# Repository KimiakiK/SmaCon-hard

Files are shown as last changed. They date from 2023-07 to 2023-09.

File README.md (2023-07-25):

# SmaCon-hard

# Features
- 

# Major Components
- STM32U575CIU6Q
Arm Cortex-M33 160MHz ROM 2MB RAM 786KB UFQFPN-48
- LCD
2.8inch 240x320 IPS ST7789 Touch GT911
- YMF825
FM音源
- 振動モータ
LD14-002

# Photos

# Parts List
- [STM32U575CIU6Q](https://mou.sr/46YhdRg)
- LCD (AliExpress)
- FM音源 YMF825 (AliExpress)
- [スピーカー](https://akizukidenshi.com/catalog/g/gP-12495/)
- [水晶振動子 12.228MHz](https://www.marutsu.co.jp/pc/i/1542722/)
- [3.5mmステレオミニジャック](https://www.marutsu.co.jp/pc/i/590750/)
- [EEPROM 1KB 25LC080C-E/MS](https://mou.sr/3XQXcYr)
- [振動モータ LD14-002](https://akizukidenshi.com/catalog/g/gP-06838/)
- [モータドライバ BD6211F](https://akizukidenshi.com/catalog/g/gI-05087/)
- [USB Type-Cコネクタ 5077CR-16SMC2-BK-TR](https://akizukidenshi.com/catalog/g/gC-14356/)
- [アナログジョイスティック JT8P-3.2T-B10K-1-16Y](https://akizukidenshi.com/catalog/g/gP-04048/)
- [タクトスイッチ(赤)](https://akizukidenshi.com/catalog/g/gP-03646/)
- [タクトスイッチ(黄)](https://akizukidenshi.com/catalog/g/gP-03650/)
- [タクトスイッチ(緑)](https://akizukidenshi.com/catalog/g/gP-03651/)
- [タクトスイッチ(青)](https://akizukidenshi.com/catalog/g/gP-03649/)
- [レバースイッチ TMHU27](https://akizukidenshi.com/catalog/g/gP-08071/)
- [リセットIC BD45285G 2.5V 50ms](https://www.marutsu.co.jp/pc/i/16146424/)
- [レギュレータ NJM2884U1-33 3.3V 500mA](https://akizukidenshi.com/catalog/g/gI-10673/)
- [ESD保護デバイス LXES11DAA2-137](https://akizukidenshi.com/catalog/g/gP-13816/)
- [フェライトビーズ BLM18PG600SH1](https://akizukidenshi.com/catalog/g/gP-04442/)
- [リセッタブルヒューズ 0.5A MF-NSMF050](https://akizukidenshi.com/catalog/g/gP-15300/)
- [NchパワーMOSFET AO3400A](https://akizukidenshi.com/catalog/g/gI-14653/)
- [FFCコネクタ 18pin 0.5mm](https://www.marutsu.co.jp/pc/i/2572902/)
- [FFCコネクタ 6pin 0.5mm](https://www.marutsu.co.jp/pc/i/2572910/)

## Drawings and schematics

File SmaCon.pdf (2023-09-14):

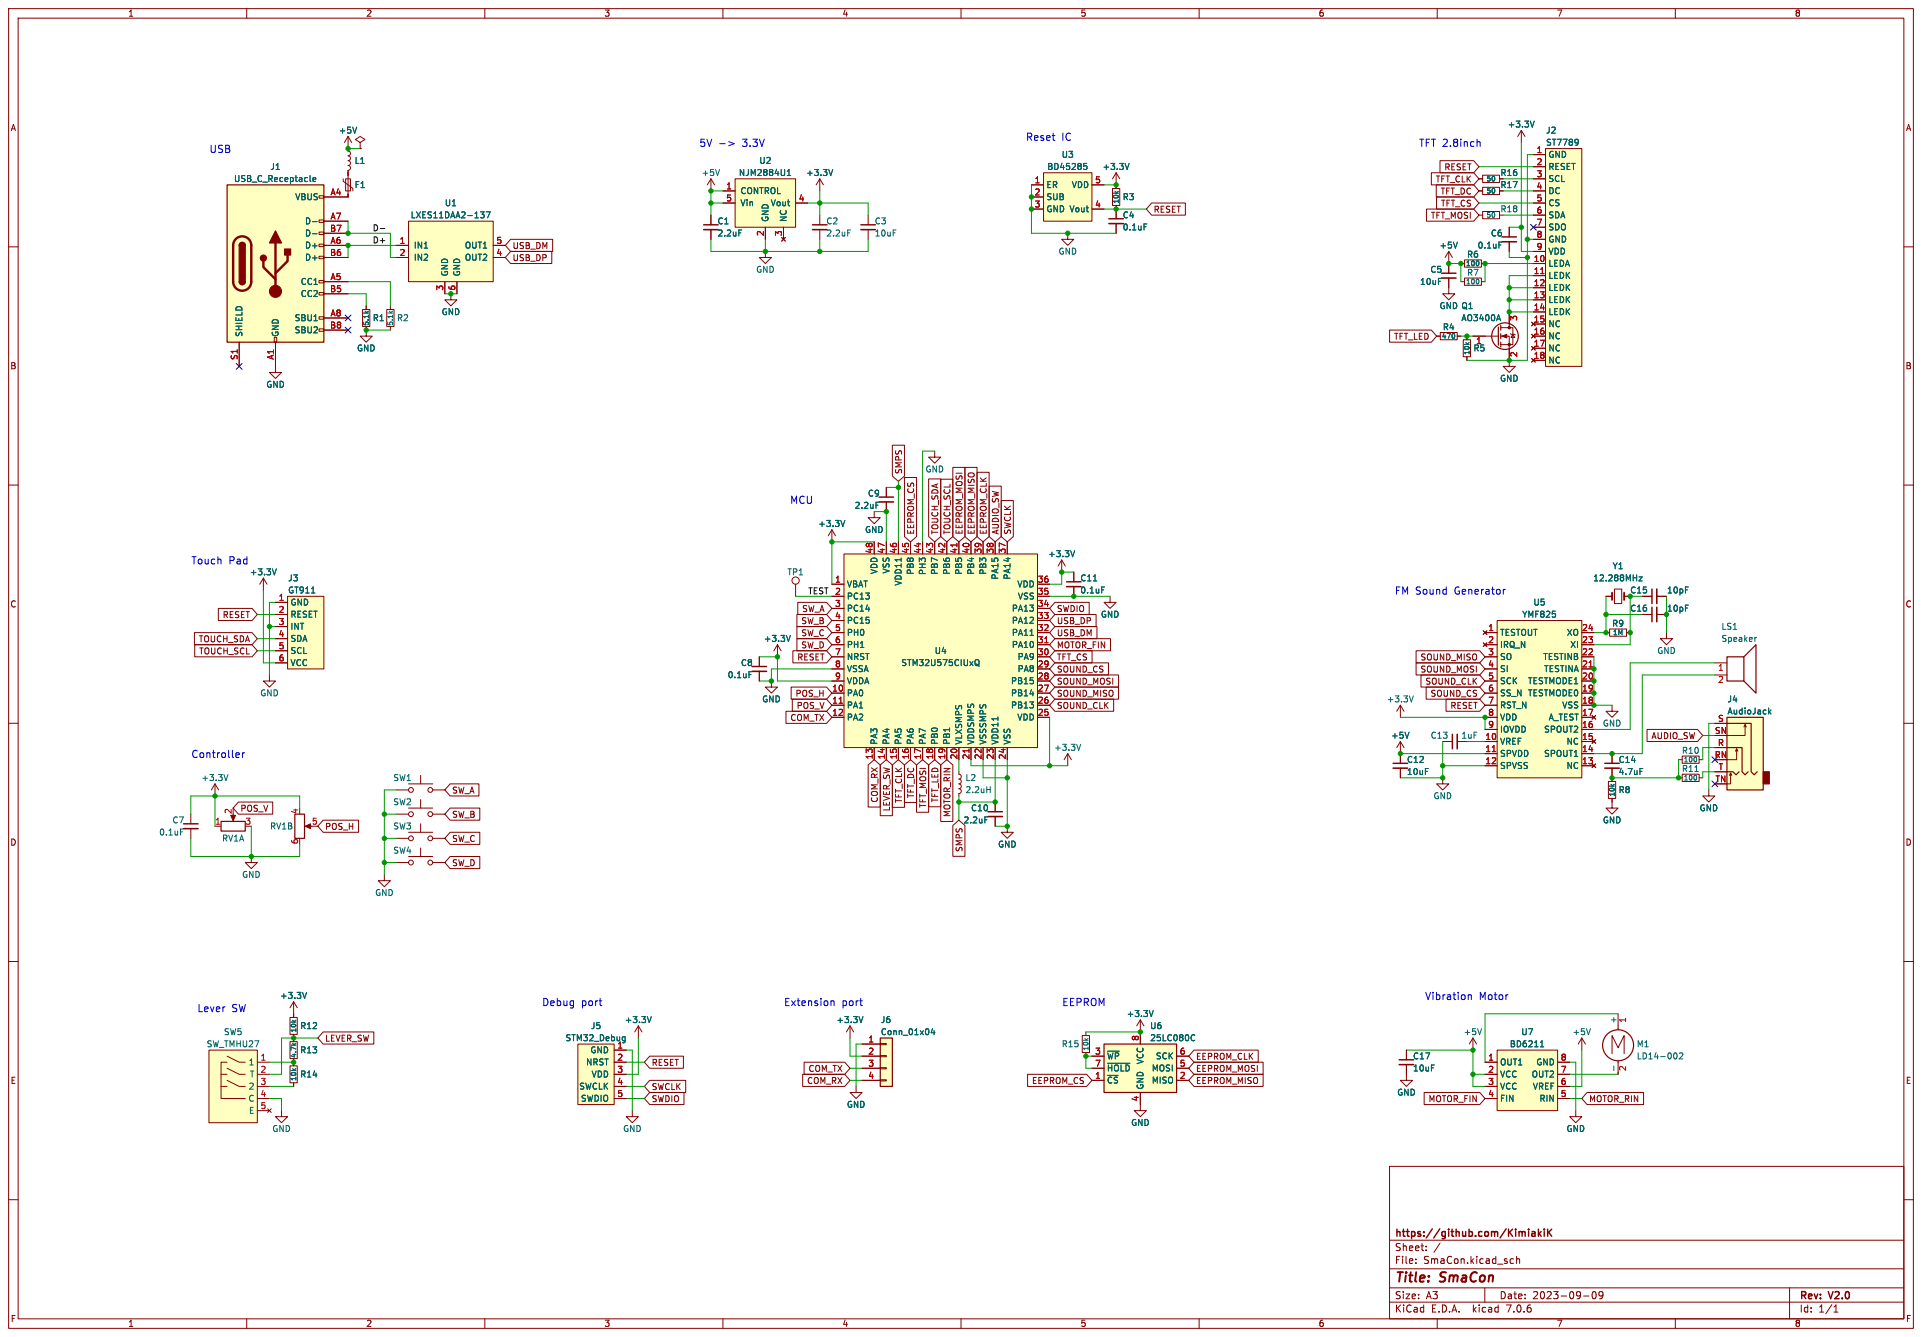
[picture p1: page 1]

LEDK 14 NC 15 NC 16 NC 17 NC 18 RESET 2 SCL 3 DC 4 CS 5 SDA 6 SDO 7 GND 8 VDD 9

LEDK 14 NC 15 NC 16 NC 17 NC 18 RESET 2 SCL 3 DC 4 CS 5 SDA 6 SDO 7 GND 8 VDD 9 R5 10k Q1 AO3400A
RESET
TFT_CLK
TFT_DC
TFT_MOSI TFT_CS

J5 STM32_Debug
GND 1 NRST 2 VDD 3 SWCLK 4 SWDIO 5

4 MOSI 5 SCK 6 ~{HOLD} 7 VCC

File: SmaCon.kicad_sch Sheet: / https://github.com/KimiakiK

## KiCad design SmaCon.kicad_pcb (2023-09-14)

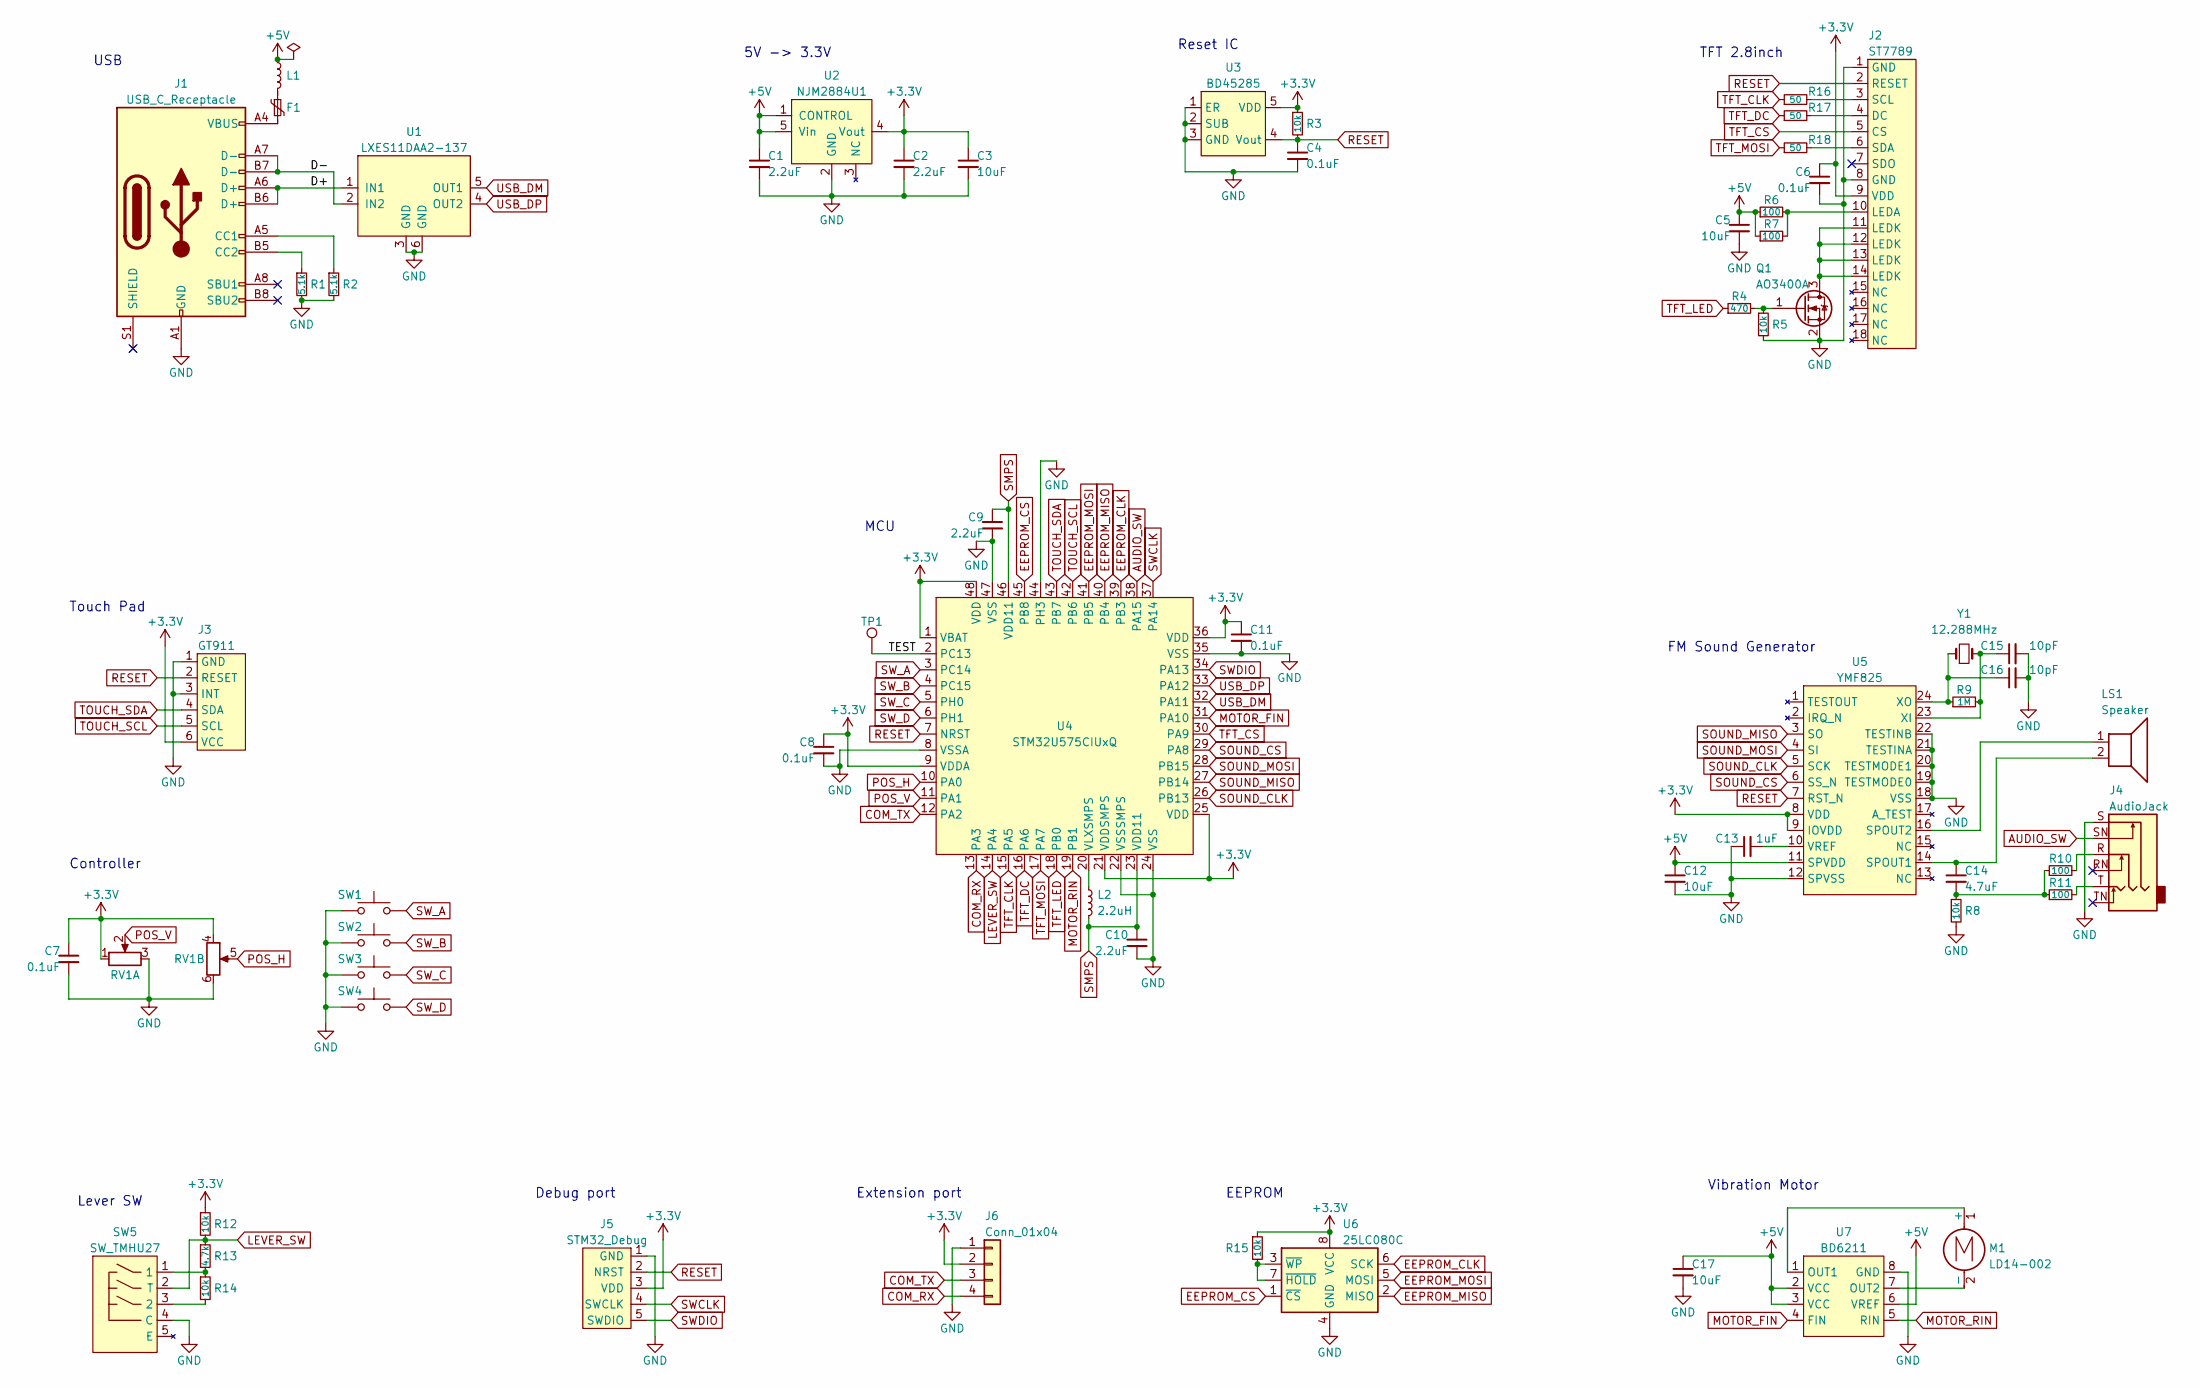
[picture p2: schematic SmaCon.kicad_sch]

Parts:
C1, C2, C9, C10: 2.2uF; 1005Metric
C3, C5, C12, C17: 10uF; 1608Metric
C4, C6, C7, C8, C11: 0.1uF; 1005Metric
C13: 1uF; 1005Metric
C14: 4.7uF; 1608Metric
C15, C16: 10pF; 1005Metric
F1: Polyfuse; 3216Metric
J1: USB_C_Receptacle; USB Type-C 5077CR-16SMC2-BK-TR
J2: ST7789; Hirose_FH12-18S-0.5SH_1x18-1MP_P0.50mm_Horizontal
J3: GT911; Hirose_FH12-6S-0.5SH_1x06-1MP_P0.50mm_Horizontal
J4: AudioJack; PJ-3420
J5: STM32_Debug; STM32_Debug_5pin
J6: Conn_01x04; PinHeader_1x04_P2.54mm_Horizontal
L1: L; 1608Metric
L2: 2.2uH; 2012Metric
LS1: Speaker; micro_speaker
M1: LD14-002
Q1: AO3400A; SOT-23
R1, R2: 5.1k; 1005Metric
R3, R5, R8, R12, R14, R15: 10k; 1005Metric
R4: 470; 1005Metric
R6, R7, R10, R11: 100; 2012Metric
R9: 1M; 1005Metric
R13: 4.7k; 1005Metric
R16, R17, R18: 50; 1005Metric
RV1: Potentiometer_Dual; JT8P-3.2T-B10K-1-16Y
SW1, SW2, SW3, SW4: SW_Push; tact_switch
SW5: SW_TMHU27
TP1: TestPoint; TestPoint_THTPad_D1.2mm_Drill0.8mm
U1: LXES11DAA2-137; LXES11D
U2: NJM2884U1; SOT-89-5
U3: BD45285; SOT-23-5
U4: STM32U575CIUxQ; QFN-48-1EP_7x7mm_P0.5mm_EP5.3x5.3mm
U5: YMF825; SSOP-24_5.3x8.2mm_P0.65mm
U6: 25LC080C; MSOP-8_3x3mm_P0.65mm
U7: BD6211; SOP-8_4.4x5.0mm_P1.27mm
Y1: 12.288MHz; Crystal_SMD_TXC_AX_8045-2Pin_8.0x4.5mm

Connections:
+3.3V: C2.1, C3.1, C6.1, C7.1, C8.1, C11.1, J2.9 (VDD), J3.6 (VCC), J5.3 (VDD), J6.2, R3.1, R12.1, R15.1, RV1.1, RV1.4, U2.4 (Vout), U3.5 (VDD), U4.1 (VBAT), U4.9 (VDDA), U4.21 (VDDSMPS), U4.25 (VDD), U4.36 (VDD), U4.48 (VDD), U5.8 (VDD), U5.9 (IOVDD), U6.8 (VCC)
+5V: C1.1, C5.1, C12.1, C17.1, L1.1, R6.1, R7.1, U2.1 (CONTROL), U2.5 (Vin), U5.11 (SPVDD), U7.2 (VCC), U7.3 (VCC), U7.6 (VREF)
/D+: J1.A6 (D+), J1.B6 (D+), U1.1 (IN1)
/D-: J1.A7 (D-), J1.B7 (D-), U1.2 (IN2)
/TEST: TP1.1, U4.2 (PC13)
AUDIO_SW: J4.SN, U4.38 (PA15)
COM_RX: J6.4, U4.13 (PA3)
COM_TX: J6.3, U4.12 (PA2)
EEPROM_CLK: U4.39 (PB3), U6.6 (SCK)
EEPROM_CS: U4.45 (PB8), U6.1 (~CS)
EEPROM_MISO: U4.40 (PB4), U6.2 (MISO)
EEPROM_MOSI: U4.41 (PB5), U6.5 (MOSI)
GND: C1.2, C2.2, C3.2, C4.2, C5.2, C6.2, C7.2, C8.2, C9.2, C10.2, C11.2, C12.2, C13.1, C15.2, C16.2, C17.2, J1.A1 (GND), J1.A12 (GND), J1.B1 (GND), J1.B12 (GND), J2.1 (GND), J2.8 (GND), J3.1 (GND), J3.3 (INT), J4.S, J5.1 (GND), J6.1, Q1.2 (S), R1.2, R2.2, R5.2, R8.2, RV1.3, RV1.6, SW1.1, SW2.1, SW3.1, SW4.1, SW5.4 (C), U1.3 (GND), U1.6 (GND), U2.2 (GND), U3.1 (ER), U3.2 (SUB), U3.3 (GND), U4.8 (VSSA), U4.22 (VSSSMPS), U4.24 (VSS), U4.35 (VSS), U4.44 (PH3), U4.47 (VSS), U5.12 (SPVSS), U5.18 (VSS), U5.19 (TESTMODE0), U5.20 (TESTMODE1), U5.21 (TESTINA), U5.22 (TESTINB), U6.4 (GND), U7.8 (GND)
LEVER_SW: R12.2, R13.1, SW5.2 (T), U4.14 (PA4)
MOTOR_FIN: U4.31 (PA10), U7.4 (FIN)
MOTOR_RIN: U4.19 (PB1), U7.5 (RIN)
unnamed: C14.2, R8.1, R10.1, R11.1
unnamed: F1.1, L1.2
unnamed: F1.2, J1.A4 (VBUS), J1.A9 (VBUS), J1.B4 (VBUS), J1.B9 (VBUS)
unnamed: J1.A5 (CC1), R2.1
unnamed: J1.B5 (CC2), R1.1
unnamed: J2.4 (DC), R17.2
unnamed: J2.10 (LEDA), R6.2, R7.2
unnamed: J2.3 (SCL), R16.2
unnamed: J2.6 (SDA), R18.2
unnamed: J4.R, R10.2
unnamed: J4.T, R11.2
unnamed: M1.1 (+), U7.1 (OUT1)
unnamed: M1.2 (-), U7.7 (OUT2)
unnamed: J2.11 (LEDK), J2.12 (LEDK), J2.13 (LEDK), J2.14 (LEDK), Q1.3 (D)
unnamed: Q1.1 (G), R4.2, R5.1
unnamed: R13.2, R14.1, SW5.1
unnamed: R14.2, SW5.3 (2)
unnamed: L2.1, U4.20 (VLXSMPS)
unnamed: C14.1, LS1.2, U5.14 (SPOUT1)
unnamed: LS1.1, U5.16 (SPOUT2)
unnamed: C13.2, U5.10 (VREF)
unnamed: C15.1, R9.2, U5.23 (XI), Y1.2
unnamed: C16.1, R9.1, U5.24 (XO), Y1.1
unnamed: R15.2, U6.3 (~WP), U6.7 (~HOLD)
POS_H: RV1.5, U4.10 (PA0)
POS_V: RV1.2, U4.11 (PA1)
RESET: C4.1, J2.2 (RESET), J3.2 (RESET), J5.2 (NRST), R3.2, U3.4 (Vout), U4.7 (NRST), U5.7 (RST_N)
SMPS: C9.1, C10.1, L2.2, U4.23 (VDD11), U4.46 (VDD11)
SOUND_CLK: U4.26 (PB13), U5.5 (SCK)
SOUND_CS: U4.29 (PA8), U5.6 (SS_N)
SOUND_MISO: U4.27 (PB14), U5.3 (SO)
SOUND_MOSI: U4.28 (PB15), U5.4 (SI)
SWCLK: J5.4 (SWCLK), U4.37 (PA14)
SWDIO: J5.5 (SWDIO), U4.34 (PA13)
SW_A: SW1.2, U4.3 (PC14)
SW_B: SW2.2, U4.4 (PC15)
SW_C: SW3.2, U4.5 (PH0)
SW_D: SW4.2, U4.6 (PH1)
TFT_CLK: R16.1, U4.15 (PA5)
TFT_CS: J2.5 (CS), U4.30 (PA9)
TFT_DC: R17.1, U4.16 (PA6)
TFT_LED: R4.1, U4.18 (PB0)
TFT_MOSI: R18.1, U4.17 (PA7)
TOUCH_SCL: J3.5 (SCL), U4.42 (PB6)
TOUCH_SDA: J3.4 (SDA), U4.43 (PB7)
USB_DM: U1.5 (OUT1), U4.32 (PA11)
USB_DP: U1.4 (OUT2), U4.33 (PA12)

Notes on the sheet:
Controller
Reset IC
Extension port
Vibration Motor
USB
EEPROM
Touch Pad
Lever SW
FM Sound Generator
Debug port
TFT 2.8inch
5V -> 3.3V
MCU

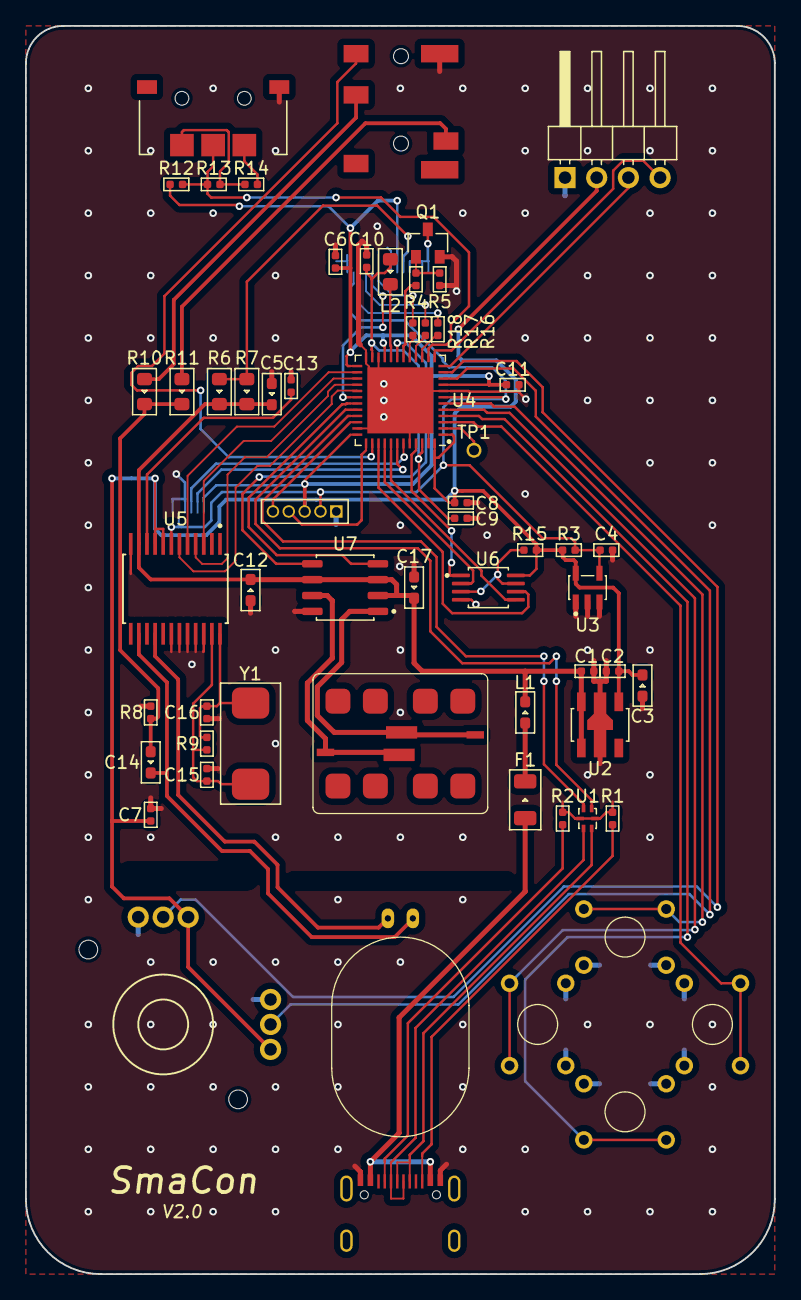
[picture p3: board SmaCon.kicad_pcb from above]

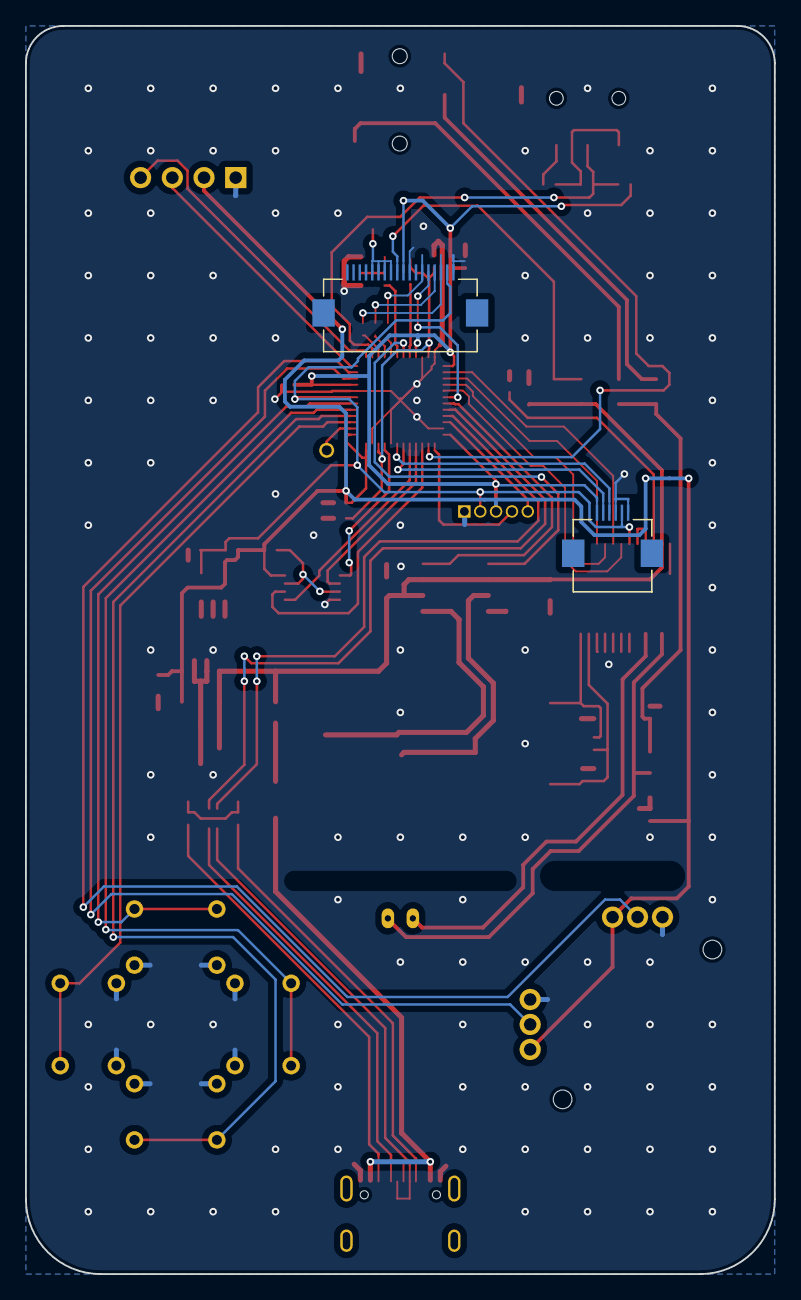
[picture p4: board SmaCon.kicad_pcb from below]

Board: 2 copper layers, 60.0 x 100.0 mm, 64 parts (2 on the bottom side), 63 nets.

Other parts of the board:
1, 2: 22b1b73a-550e-4fe2-9098-770367972fd8

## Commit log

2023-02-12 プロジェクト作成
    [SmaCon.kicad_pcb, SmaCon.kicad_sch]
2023-07-13 回路図作成
    [SmaCon.kicad_sch]
2023-07-13 EEPROMに変更、マイコン型番変更
    [SmaCon.kicad_sch]
2023-07-19 部品選定
    [SmaCon.kicad_sch]
2023-07-25 基板 V1.0
    [SmaCon-B_Cu.gbl, SmaCon-B_Mask.gbs, SmaCon-B_Paste.gbp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]
2023-08-05 基板 V1.1
    [SmaCon-B_Cu.gbl, SmaCon-B_Mask.gbs, SmaCon-B_Paste.gbp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]
2023-08-21 基板 V1.2
    [SmaCon-B_Cu.gbl, SmaCon-B_Mask.gbs, SmaCon-B_Paste.gbp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]
2023-09-14 基板 V2.0
    [SmaCon-B_Cu.gbl, SmaCon-B_Mask.gbs, SmaCon-B_Paste.gbp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]
